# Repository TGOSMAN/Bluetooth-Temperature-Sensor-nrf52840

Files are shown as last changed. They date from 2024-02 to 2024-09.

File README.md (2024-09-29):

```python
import numpy as np
import matplotlib.pyplot as plt
import scipy.signal as signal
```

# Bluetooth Thermometer Design Report

This Notebook, documents the design process and considerationg in making this bluetooth thermometer. The purpose of this project was to be an exercise for PCB design in an IoT environment, and apply the basic stages of product development as an engineer, and enable further development in skills with electronics, DSP, digital design and embedded systems.

### Product Summary
The thermometre device produce, takes a reading from an analogue temperature sensor and broadcast's in an bluetooth low energy advertising packet.Simultaneously, the temperature reading is displayed a quantised temperature level across a row of RGB LED's which can have the colour customised with a BLE connection to the thermometer itself. 
***

## Product Planning
At this stage of development, the functional goals of the product are set. This sets a frameworkfor testing the performance in the later stages, and provides a target to work towards when iteratively improving the systems within the product. The considerations were primarily focused on the user interace with the device due it being the only output of the system and on of the two inputs to the system, hence a strong set of criteria was required.

### Requirements Analysis
|Requirements|Constraints|Needs|
|:-:|:-:|:-:|
|The temperature can be determined visually|Power can only be sourced from a battery or a DC converted source (e.g USB, USB-C, etc)|The device must be able to have customisability for it to blend with its surroundings or to match user preference|
|A alternative user interface can provide user's a reading with an acccuracy of 2 degrees Celsius|The device must have a ridid body so that it is robust and can be mounted|The device only needs to be supplied power for it to start working, with no setup involved|
|The Product must be under $30 to produce|||

### Problem Statement
The problem is to design a product that will assist users to determine the ambient room temperature. The product should give users multiple options to read the temperature, that can be selected based on the effort levels. The product should allow users to customise display methods based on there needs and allow for the product to blend with surrounding home decor. The product may offer many features, however, the central challenge is to measure the temperature and communicate it to a user in different formats at the same time.
***

## Conceptualisation
At this stage, the thermometer's main components and aspects are selected and given detail to assist the detailed design stage. The focus is the overall functions of the product and how that will translate to hardware/software for implementation.

### Concept
The produce developed will have an LED strip that can show the temperature with the LED's colour arrangement along the strip, similar to that of a mercury thermometer.The colour of the LED's will be customisable to match a surrounding colour theme or the user's preference. 

The interface to change the internal settings of the device, will occur over a wireless domain(Bluetooth LE) to provide a low effort requirment and to meet the standards of the 21st century. Since a wireless connection will be required to configure the settings, an efficient use of this domain would be to also communicate the temperature reading with a numerical format. This will allow for a greater accuracy in the reading that will originate from the sensor subsytem itself.

The device will be powered by a wired connection, with a common USB-Type C Connector to supply DC power to the device. This was due to the higher power consumption of LEDs which would drain the battery rather quickly, hence a USB-C provides a highly accessible option for users to connect. 

### High Level Design
As previously discussed the product will be supplied by a USB type-C port to a microcontroller that can interface over bluetooth low energy and via digital signalling with the other subsystems. Each of the other subsytems will be powered by the same USB-C source which will be set to the default 5V supply. 

The temperature sensor will be an analogue sensor from which an ADC will sample it and use this data to then configure the LEDs and advertising packet. The LEDs will be an RGB type to allow for colour changes and contrast to be displayed. A diagram of this is shown below.

<center><image src= "HLD.png" width=45%></image><center>

***

## Hardware Design

### LEDs
The LED selected was the WS2182b. This was selected for its programmable RGB combination and brightness. The WS2182B will be able to take as an input a 24 bit PCM coded stream of data to reflect each of the RGB level for each LED. After the first packet is taken the following packet is transmitted to the next LED. This will allow for the microcontroller to be able to change the colour and brightness of each individual LED without requiring 24 PWM channels continously running. Hence this method is an efficient use of the MCU without a large range of PWM peripherals or an LED controller. Since the signally for the LED's is above 3.3V a level shifter will be required for signally to be shifted and sent to the LED's effectively.

### Microcontroller
The nrf52840 was chosen due to its low cost and detailed documentation available. The Nordic Semiconductor SiC contains an Arm Cortex M4 (64Mhz) CPU  with an integrated 2.4 Ghz Transceiver and Radio Controller that can be easily intefaced with software. This will enable the device to have firmware easily implement and control the BLE transmission mode (2Mbps ,1Mbps etc), along with the bluetooth profile of the device.

The SiC has a 4 Channel PWM Generator that is integrated with DMA for fast and effient signalling. This feature will be used along with the internal PPI(Peripheral Peripheral Interconnect)(Figure 2) to signal to WS2812b LED's and control the sequence period when it is updated.

The NRF52840 has a 12bit ADC placed internally with a maximum sampling rate of 200ksp/s  and a variable analogue gain channel to customise the quantisation level size of the ADC. This function will be used to place the voltage range of the analogue temperature sensor to the gain level required allowing for an optimised resolution. This adc will directly sample the temperature sensor connected to the pin.

### Power Supply
The power supply chosen was an LDO (TLV2117) to ensure a stable and low noise 3.3V source was supplied to the NRF52840, this was chosen due to a USB type-C power source having a high noise level. However, since the WS2812B LED's are a have a high voltage range and are a digital system, the noise level directly from the USB Type-C 5V suppy will suffice to power them.

### Sensor 
The TMP235A was selected as the temperature sensor to be used for its simplicity and low cost. The accuracy of the sensor is $\pm2\degree C$, which will match the criteria identified from the requirements analysis.This sensor can be supplied directly from 3.3V. However, following the data sheet recommendation a 0.1 $\mu F$ decoupling capacitor will be connected to reduce the amount of digital noise that couples to the analogue sensor output. 
The sensor utilises thermal diodes to produce a voltage variation proportional to the temperature. The output of the TMP236 is a buffered output meaning with an output driver designed for direct connection to ADC's and can supply a 1000pF load, hence an interfacing circuit is not required. The specification of the TMP236 specifies for the temperature region being considered the voltage output is $19.5mV / \degree C$ with an offset voltage of 400mV. This can also be written as a linear equation as shown below: 
$$V = 0.0195T + 0.4$$

### PCB Layout Considerations
Key Considerations in the layout of this design were to avoid EMI and transmissoin line effects. Due to the board shape being a long board and each LED being spread evenly along the long dimension of the board.

***

## Firmware Development

### Firmware Structure
The firmware has been written with the use of the nordic NRFx Drivers and the Zephyr real time operating system. The Zephyr RTOS will create and maintain the BLE stack, whilst also allowing for easy creation of threads and memory for efficient power usage. The structure of this firmware contains two main threads, one to manage the notifications and LED signalling of the device and the other ot manage the filtering and ADC use of the device. The Data will be passed between the two threads in a threadsafe manner with the use of a message que. A messsage Que is a simple linked list data structure thats is used to pass a specific struct containing data, between threads. The overall strucutre is illustrated below:

### BLE Configuration
The configuration used for the bluetooth low energy model is a server connectable device. The GATT model includes the environmental sensing primary servie with a temperature charactiristic and a client configuration descriptor within it. This is so that the device can connect and enable regular updates remotely.

### LEDs Signalling
The LEDs chosen are the WS2812B's which have there own RZ (Return to Zero) communication protocol shown in the first figure below. To enable this protocol to effictively the PWM drivers need3e to be used for a custom duty cycle (since this is where the information is stored). In addition to the PWM drivers, a PPI bus connected with a timer to allow for data to be segmented into 24 bit packets to address each LED. The PPI enables the timer and PWM to be reset without a direct CPU intervention. 

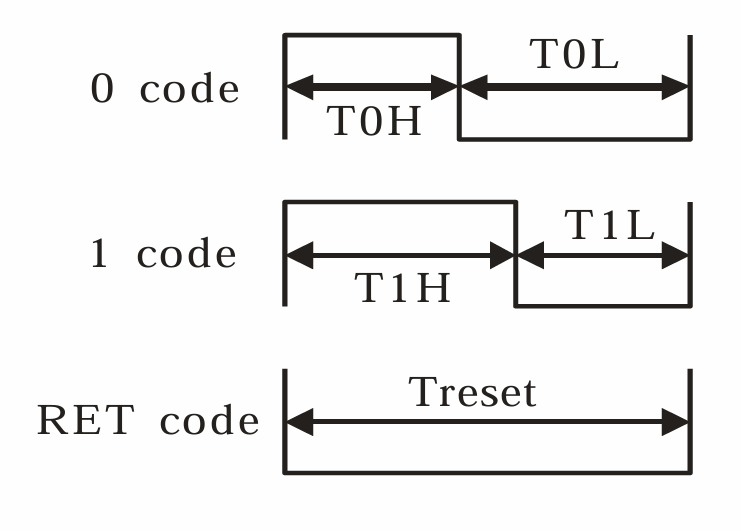
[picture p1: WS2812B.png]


|Symbol|Timing|
 |--|--|
 |T0H|0.4 us|
 |T1H|0.8 us|
 |T0L|0.85 us|
 |T1L|0.45 us|
 |Res| $\ge$ 50us|

The individual LED's each will recieve a packet of 24 bits with 8 bits dedicated to the intensity of each RGB component send by .The WS2812B will store the value of the packet last received also allowing for the LED's to remain unchanged until they are updates with a new packet. This will allow for further power saving since LED signalling will only need to occur at a custom rate and can be slowed down to reduce overal power consumption of the device. With this method the default colours of contrast chosen were red and blue to allow for a clear indication to begin. 

### ADC Sampling
The ADC peripheral in the nRF52840 is a Successive Approximation ADC that has a adjustable resolution and gain. The resolution was set to 12bit with a 2 hz sampling rate in a blocking method due to the low chance that the output will change at high speed. The ADC sampling and conversion is completed in a seperate thread and sent over a workque to the bluetooth and lighting thread to ensure maximum power efficiency. However due to this multithreaded approach the sampling rate will not be precisely 2Hz but have a small variation due to the surrounding instrucutions however this will have minimal magnitude in comparison to the sampling period when the CPU uses a 64Mhz clock. 

The conversion is made by the CPU by first making the data conversion to mV with the formula: $V = Sample \cdot\frac{Gain}{Reference} \cdot \frac{1}{2^{12}}$ 

### Digital Filter Design

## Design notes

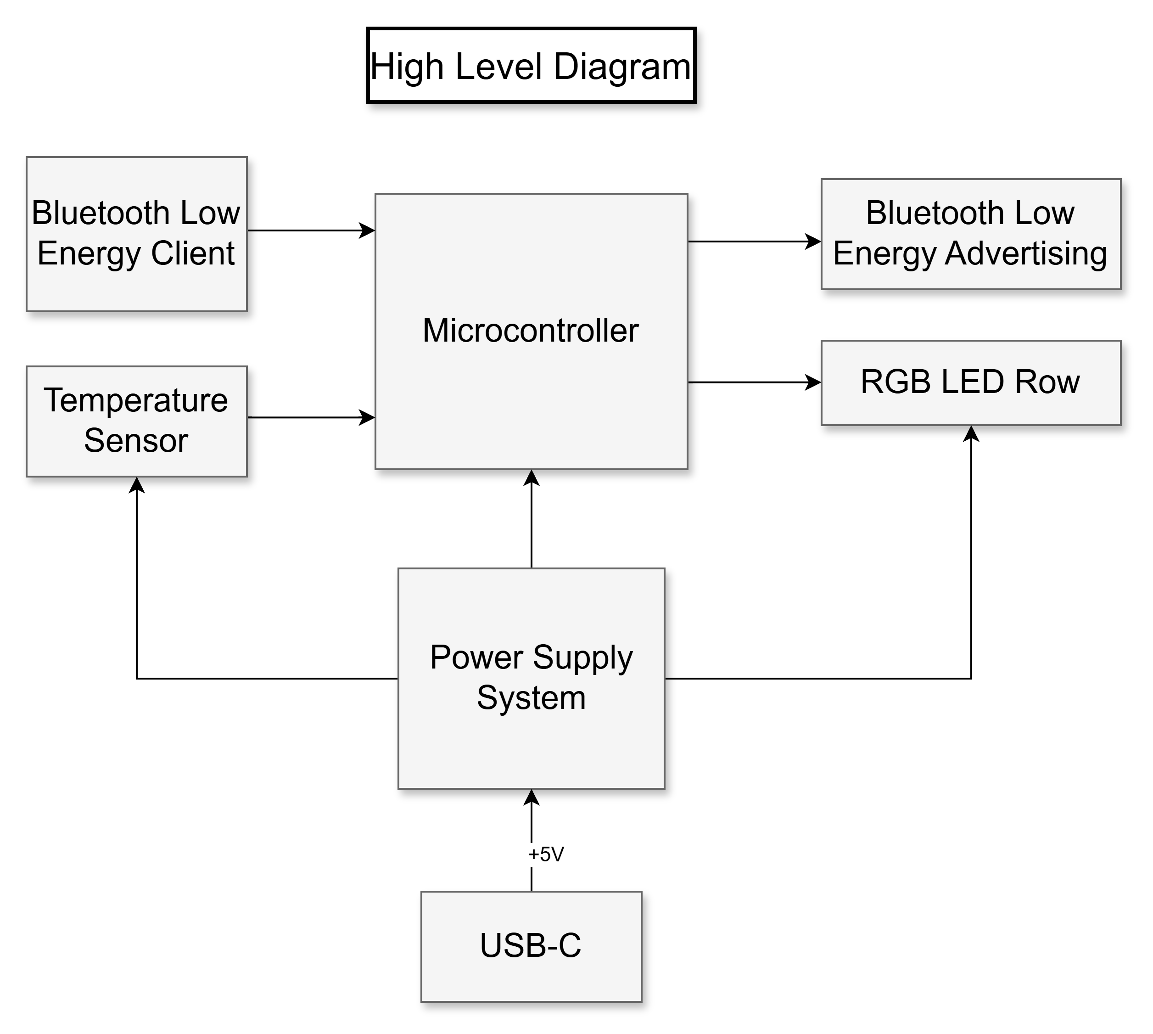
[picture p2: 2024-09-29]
HLD.png

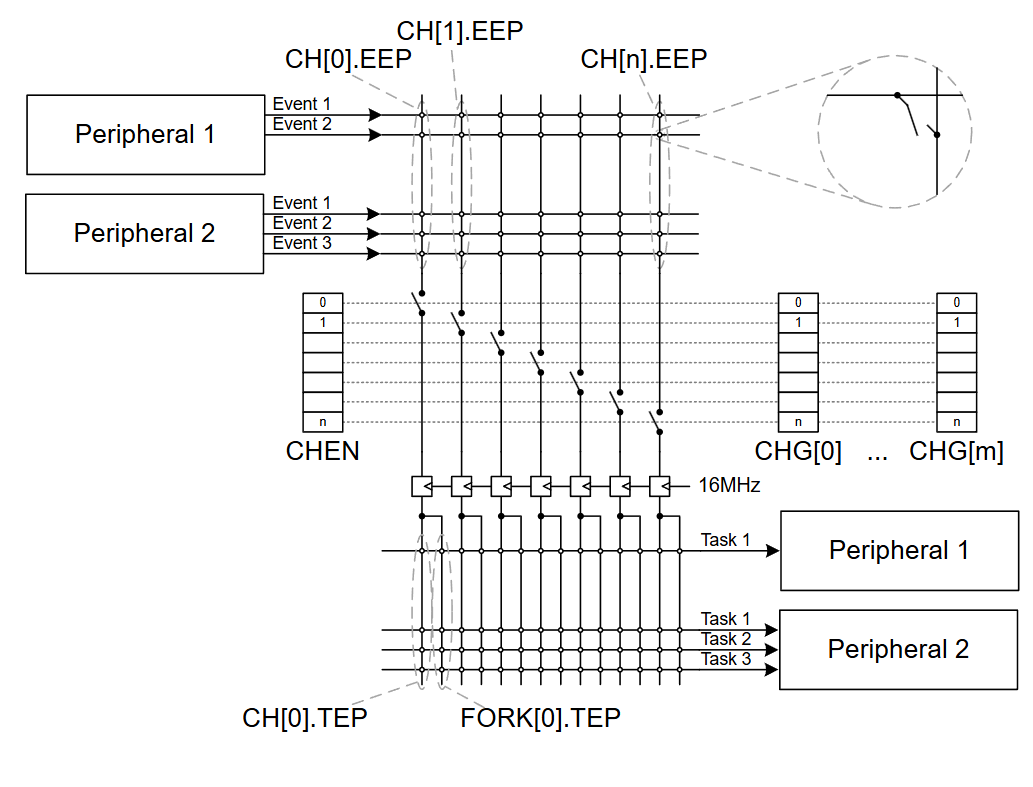
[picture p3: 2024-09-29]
PPI.png

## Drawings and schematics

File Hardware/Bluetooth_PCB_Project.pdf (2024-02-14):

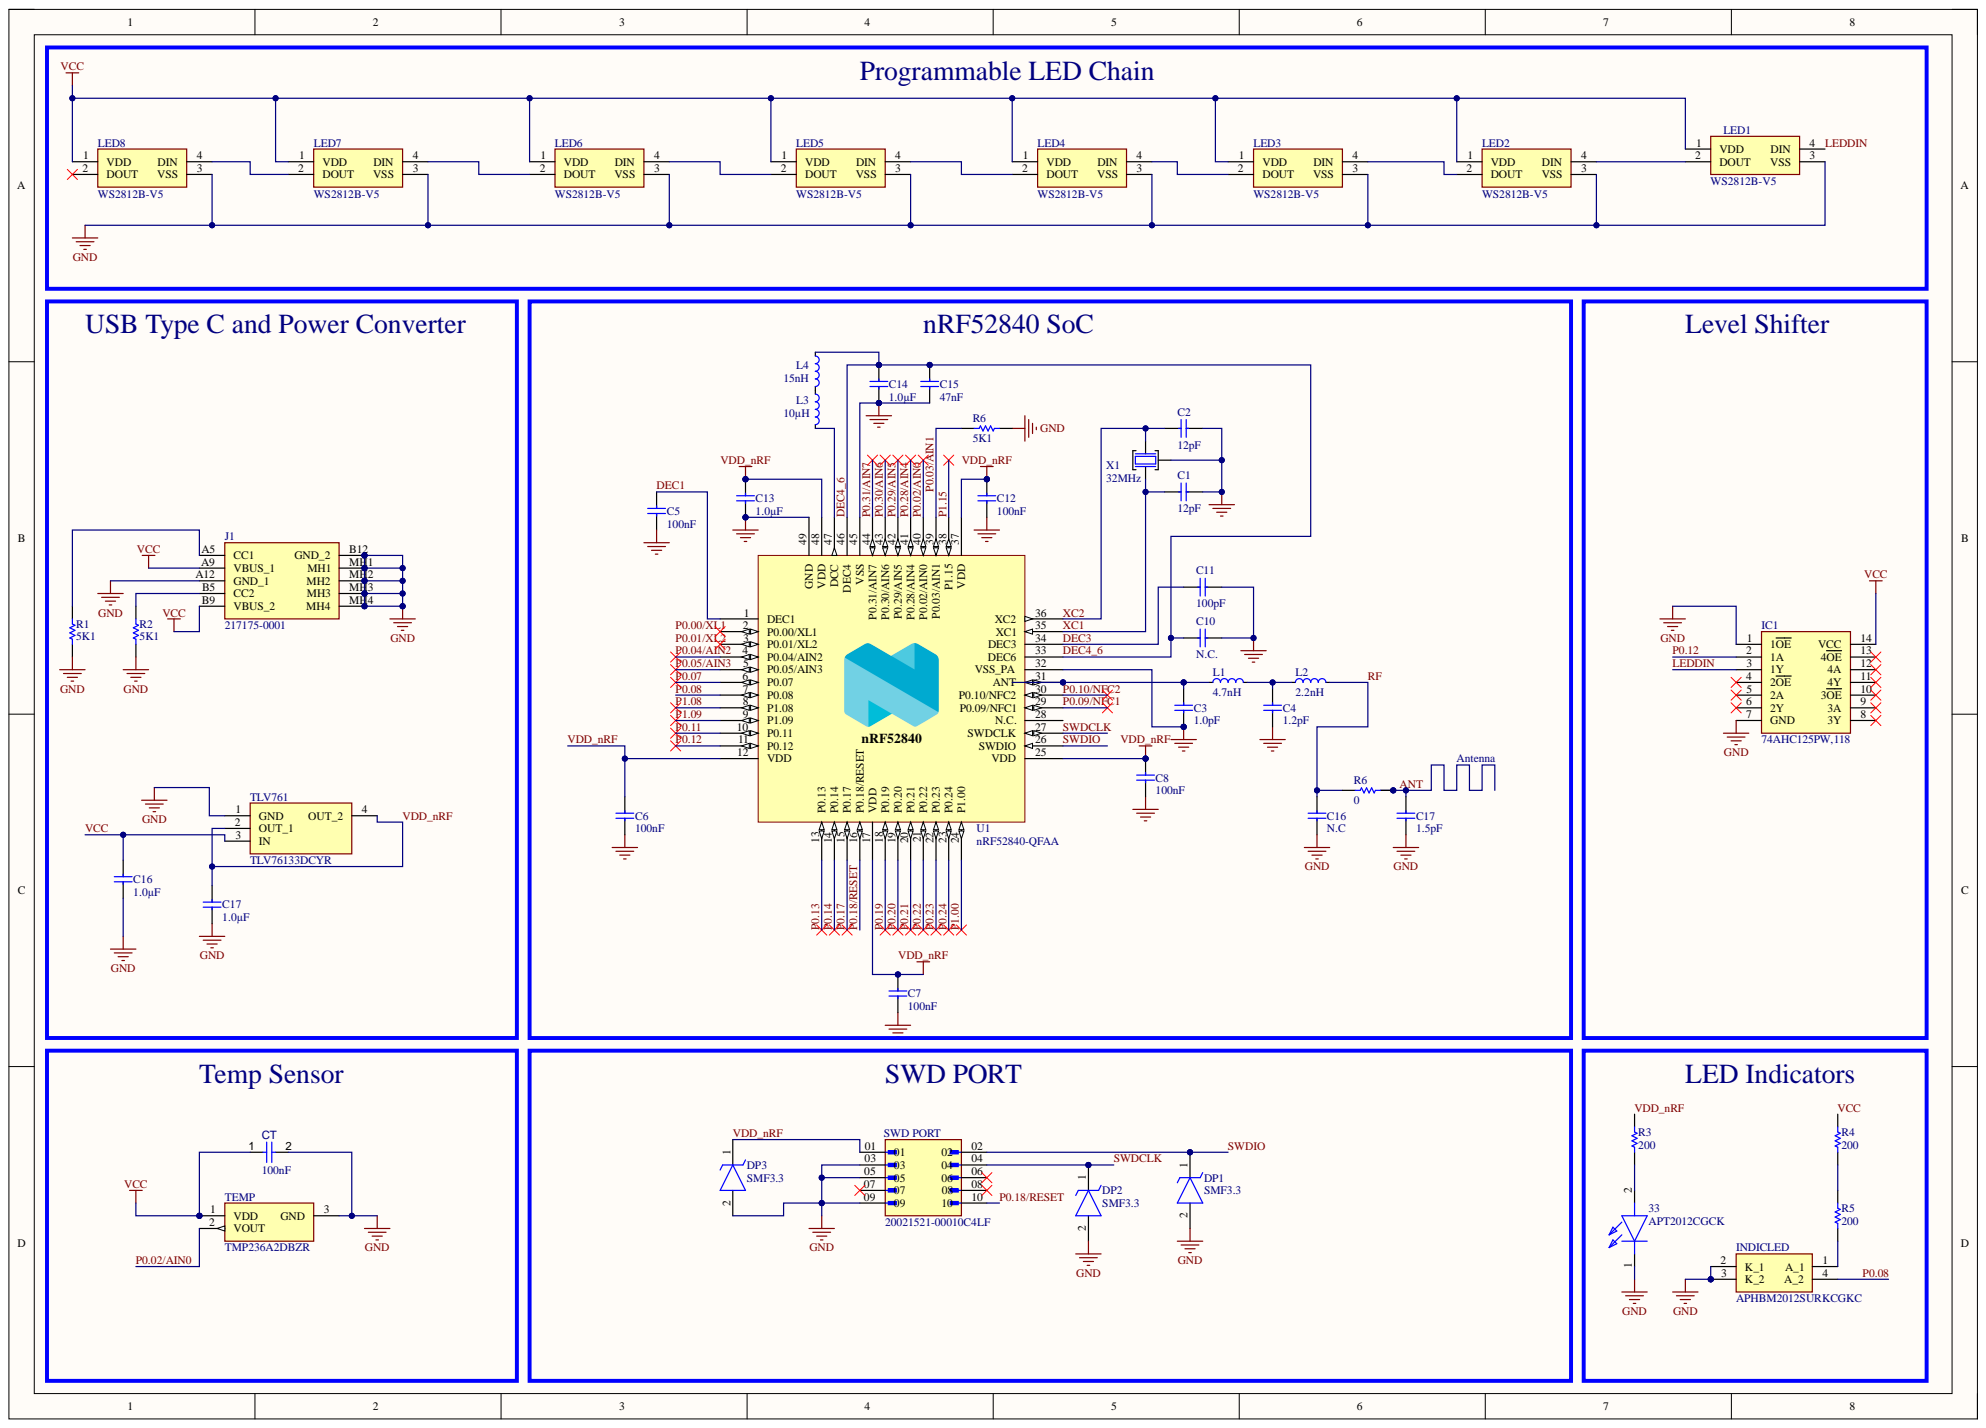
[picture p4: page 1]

VBUS_2 B9

5K1 | VCC

VDD 1

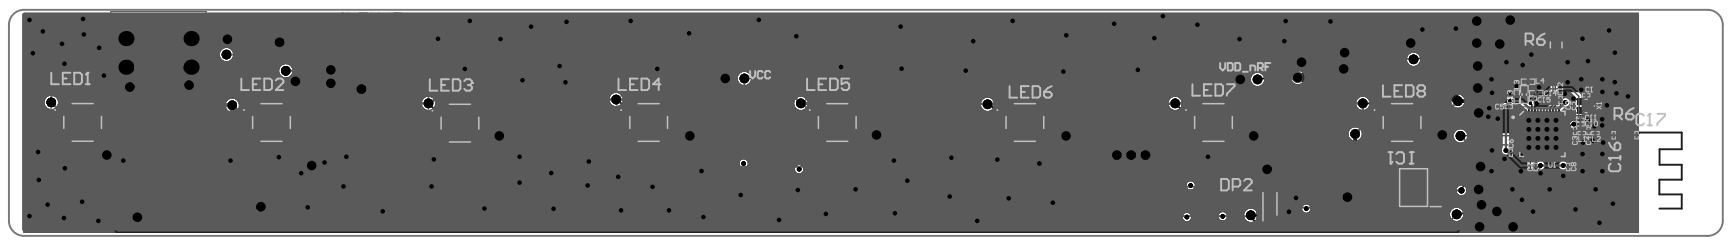
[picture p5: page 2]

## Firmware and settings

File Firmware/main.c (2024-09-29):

#include "hal/nrf_pwm.h"
#include <nrfx_example.h>
#include <nrfx_pwm.h>
#include <stdbool.h>
#include <stdint.h>
//#include <zephyr/drivers/adc.h>
#include <zephyr/drivers/pwm.h>
#include <zephyr/kernel.h>
#include <zephyr/sys/printk.h>
#include "drivers/nrfx_errors.h"
#include <nrfx_glue.h>
#include <nrfx_saadc.h>
#include <helpers/nrfx_gppi.h>
#include <zephyr/bluetooth/bluetooth.h>
#include <zephyr/bluetooth/gap.h>
#include <zephyr/bluetooth/gatt.h>
#include <zephyr/bluetooth/uuid.h>
#include <zephyr/bluetooth/addr.h>
//#include "saadc_examples_common.h"
#include <nrfx_log.h>


#define NRFX_LOG_MODULE                 EXAMPLE
#define NRFX_EXAMPLE_CONFIG_LOG_ENABLED 1
#define NRFX_EXAMPLE_CONFIG_LOG_LEVEL   3
#define STACKSIZE 1024
#define THREAD0_PRIORITY 7
#define THREAD1_PRIORITY 7
#define PWM_INST_IDX 0
#define ARRAYSIZE 192
//#define CH0_AIN ANALOG_INPUT_TO_SAADC_AIN(ANALOG_INPUT_A0)
/* BLUETOOTH SETUP */
/** @brief Temperature Sensor Characteristic UUID. */
#define BT_UUID_TEMPSENSOR_VAL BT_UUID_128_ENCODE(0x00001523, 0x1212, 0xefde, 0x1523, 0x785feabcd123)
#define BT_UUID_TEMP_MYSENSOR_VAL \
	BT_UUID_128_ENCODE(0x00001526, 0x1212, 0xefde, 0x1523, 0x785feabcd123)
#define BT_UUID_TEMPSENSE BT_UUID_DECLARE_128(BT_UUID_TEMPSENSOR_VAL)
#define BT_UUID_TEMP_MYSENSOR       BT_UUID_DECLARE_128(BT_UUID_TEMP_MYSENSOR_VAL)
//Bluetooth Naming Structure
#define DEVICE_NAME CONFIG_BT_DEVICE_NAME
#define DEVICE_NAME_LEN (sizeof(DEVICE_NAME) - 1)
/* PWM SETUP*/
/**
 * @brief Symbol specifying number of times that each duty cycle is to be repeated (after being
 *        played once) and is strictly correlated with the "breath" effect speed.
 */
#define VALUE_REPEATS 0UL
/** @brief Symbol specifying number of loops (breaths) to be performed. */
#define NUM_OF_LOOPS 1UL
/**
 * @brief Symbol specifying number of playbacks to be performed. In this example couple of
 *        playbacks might be considered as one loop.
 */
#define PLAYBACK_COUNT 1UL

/* 
*   @brief Temperature Sensor Notification Properties to be updated and stored
 */
static bool notify_sensor_enabled = false;
static void tempsense_ccc_mysensor_cfg_changed(const struct bt_gatt_attr *attr,
				  uint16_t value)
{
    // Get the value for the the notifciation status and store it in the global variable
	notify_sensor_enabled = (value == BT_GATT_CCC_NOTIFY);
}


struct bt_conn *my_conn = NULL;
//Advertising Packet
static const struct bt_data ad[] = {
        BT_DATA_BYTES(BT_DATA_FLAGS, BT_LE_AD_NO_BREDR),
        BT_DATA(BT_DATA_NAME_COMPLETE, DEVICE_NAME, DEVICE_NAME_LEN),
        BT_DATA_BYTES(BT_DATA_UUID16_ALL, 0x1a, 0x18),
        //BT_DATA(BT_DATA_SVC_DATA16, 0x18, 0x1a), // UUID for Temperature Sensor
       //BT_DATA(BT_, 0x18,0x1a), // UUID for Temperature Sensor
};
int temperature = 0;
static struct bt_le_adv_param *adv_param = BT_LE_ADV_PARAM(
            (BT_LE_ADV_OPT_CONNECTABLE |
            BT_LE_ADV_OPT_USE_IDENTITY), /* Connectable advertising and use identity address */
            BT_GAP_ADV_FAST_INT_MIN_1, /* 0x30 units, 48 units, 30ms */
            BT_GAP_ADV_FAST_INT_MAX_1, /* 0x60 units, 96 units, 60ms */
            NULL); /* Set to NULL for undirected advertising */
//Scan Response Packet
static const struct bt_data sd[] = {
        //BT_DATA(BT_DATA_UUID16_ALL,0x1a,0x18),
       //BT_DATA_BYTES(BT_DATA_UUID16_ALL,0x2a,0x6e),
       //BT_DATA(BT_DATA_SVC_DATA16, 0x18, 0x1a), // UUID for Temperature Sensor
};

BT_GATT_SERVICE_DEFINE(tempsensor_svc, BT_GATT_PRIMARY_SERVICE(BT_UUID_ESS),

	/*BT_GATT_CHARACTERISTIC(BT_UUID_TEMP_MYSENSOR, BT_GATT_CHRC_NOTIFY, BT_GATT_PERM_NONE, NULL,
			       NULL, NULL),*/
    BT_GATT_CHARACTERISTIC(BT_UUID_TEMPERATURE, BT_GATT_CHRC_READ | BT_GATT_CHRC_NOTIFY, BT_GATT_PERM_NONE, NULL, NULL, NULL),
	BT_GATT_CCC(tempsense_ccc_mysensor_cfg_changed, BT_GATT_PERM_READ | BT_GATT_PERM_WRITE),

);

//Bluetooth connection callback's
void on_connected(struct bt_conn *conn, uint8_t err)
{
    if (err) {
        //LOG_ERR("Connection error %d", err);
        return;
    }
    //LOG_INF("Connected");
    my_conn = bt_conn_ref(conn);
    return;
    /* STEP 3.2  Turn the connection status LED on */
}

void on_disconnected(struct bt_conn *conn, uint8_t reason)
{
    //LOG_INF("Disconnected. Reason %d", reason);
    bt_conn_unref(my_conn);
    return;
    /* STEP 3.3  Turn the connection status LED off */
}



struct bt_conn_cb connection_callbacks = {
    .connected              = on_connected,
    .disconnected           = on_disconnected,
};

int tempsensor_send_sensor_notify(uint32_t sensor_value)
{
	if (!notify_sensor_enabled) {
		return -EACCES;
	}

	return bt_gatt_notify(NULL, &tempsensor_svc.attrs[2], 
			      &sensor_value,
			      sizeof(sensor_value));
}


//create a global PWM instance
nrfx_pwm_t pwm_instance1 = NRFX_PWM_INSTANCE(PWM_INST_IDX);
typedef struct {
    int temp_reading;
} SensorReading;
K_MSGQ_DEFINE(device_message_queue, sizeof(SensorReading), 16, 4);
// Global PWM configuration setup
// 1 PWM period is 1.25us, clco8k period is 62.5ns
// automatic stepping
nrfx_pwm_config_t config1 = {    
    .output_pins = {LED1_PIN},
    .pin_inverted = {1},
    .irq_priority = 7,
    .base_clock = NRF_PWM_CLK_16MHz,
    .count_mode = NRF_PWM_MODE_UP,
    .top_value = 20,
    .load_mode = NRF_PWM_LOAD_COMMON,
    .step_mode = NRF_PWM_STEP_AUTO,
    .skip_gpio_cfg = 0
};

// Mutex definition of variable synchronisation/ control over critical code section timing
K_MUTEX_DEFINE(key);
nrf_pwm_values_common_t pwm_val []=
{
    0, 0, 0, 0, 0, 0, 0, 0,0, 0, 0, 13, 6, 13, 6, 13, 6, 6, 13, 13, 13, 13, 6, 13
};
static nrf_pwm_values_common_t reset_seq [55] = {0};
nrf_pwm_values_common_t pwm_array_val [192] = {0};
nrf_pwm_values_common_t pwm_array_val2 [192] = {0};

// Led Array Build Function:
/*
Inputs:
    nrf_pwm__values_common_t *array: Pointer to array[0] to store signal PWM duty cycles as one big block to send as a continouse signal
    int lednumber: number where it sits in the LED strip 0-7 to place the colour sequnce in teh correct order
    nrf_pwm__values_common_t *coloursignal: pointer to coloursignal[0] which is the 24 element array that holds the colour value for 1 LED
Outputs:
    none
Description:
    concatenates each LED colour setup array as one big block of a pwm duty cycle sequence to be sent as a continous signal due to the WS2812 signalling
*/
void configurePPI(void){
    uint8_t pwm_stop_ppi_channel;
    nrfx_err_t err = nrfx_gppi_channel_alloc(&pwm_stop_ppi_channel);
    if (err != NRFX_SUCCESS) {
        LOG_ERR("nrfx_gppi_channel_alloc error: %08x", err);
        return;
    }
    nrfx_gppi_channel_endpoints_setup(pwm_stop_ppi_channel,nrfx_pwm_event_address_get(&pwm_instance1, NRF_PWM_EVENT_SEQEND0),
                                  nrf_pwm_task_address_get(pwm_instance1.p_reg,  NRF_PWM_TASK_STOP));

    nrfx_gppi_channels_enable(BIT(pwm_stop_ppi_channel));
}
void ledarraybuild(nrf_pwm_values_common_t *array,int lednumber,nrf_pwm_values_common_t *coloursignal){
    int base;
    base = 24*lednumber;
    for(int i = 0; i < 24; i++){
        array[base + i] = coloursignal[i];
    }
    return;
}

// Colour Sequence Function:
/*
Inputs:
    nrf_pwm__values_common_t *val: Pointer to val[0], which is a 24 element array of uint16_t values to store individual duty cycles in
    uint8_t red: Red component of a colour RGB hex code for ease of use
    uint8_t green: Green component of a colour RGB hex code for ease of use
    uint8_t blue: Blue component of a colour RGB hex code for ease of use
    
Outputs:
    none
Description:
    Adds appropriate duty cycle values in an array to represent a colour for one LED from a hex code
    to match the WS2812 signalling protocol. This is inverted as it appears the PWM signal has an 
    an inversion at some point. High should be VH for ~800ns, Low should be VH for ~400ns, this is designated
    from the hex code with the correct ordering as well.
*/
void colour_sequence(nrf_pwm_values_common_t *val, uint8_t red, uint8_t green, uint8_t blue){

    for(int i = 7; i >= 0; i--){
        //redblock
        if((red&(0x80>>i))){
            val[i + 8] = 5;
        } else {
            val[i + 8] = 15;
        }
    
        // blue block
        if((blue&(0x80>>i))){
            val[i + 16] = 5;
        } else {
            val[i + 16] = 15; 
        }
        // green block
        if((green&(0x80>>i))){
            val[i] = 5;
        } else {
            val[i] = 15;
        }
    }
    return;
}

//once PWM has a loop event this is triggered to setup a looped PWM.-> we need to change this to not be looping
//currently set to only loop once
static void pwm_handler(nrfx_pwm_evt_type_t event_type, void * p_context)
{
    nrfx_pwm_t * inst = p_context;

}


static void ledupdate(uint32_t highcolour, uint32_t lowcolour, int level){
    static nrf_pwm_values_common_t pwm_array_val [192] = {0};
    nrf_pwm_sequence_t const seq_set =
    {
        .values = {pwm_array_val},
        .length = NRFX_ARRAY_SIZE(pwm_array_val),
        .repeats = VALUE_REPEATS,
        .end_delay = 0
    };
    //PWM0->PSEL
    for(int i = 0; i < 8; i++){
        colour_sequence(pwm_val, (uint8_t)((highcolour&(0xFF000000))>>24), (uint8_t)((highcolour&(0x00FF0000))>>16), (uint8_t)((highcolour&(0x0000FF00))>>8));
        
        //colour_sequence(pwm_val, 0x01, 0x0F, 0x01);
        ledarraybuild(pwm_array_val, i, pwm_val);
    }
    for(int i = 0; i < level; i++){
        colour_sequence(pwm_val, (uint8_t)((lowcolour&0xFF000000)>>24), (uint8_t)((lowcolour&0x00FF0000)>>16), (uint8_t)((lowcolour&0x0000FF00)>>8));
        //colour_sequence(pwm_val,0x0F, 0x00, 0x00);
        ledarraybuild(pwm_array_val, i, pwm_val);
    } 

    nrfx_pwm_simple_playback(&pwm_instance1, &seq_set, PLAYBACK_COUNT, NRFX_PWM_FLAG_LOOP);

    
    //nrfx_pwm_stop(&pwm_instance, true);
    //nrfx_pwm_sequence_update(&pwm_instance, 0,&seq_set);
    return;
}


//Thread to change the colour based on the ADC value/ Temperature
void thread0(void)
{
    #if defined(__ZEPHYR__)
    IRQ_CONNECT(NRFX_IRQ_NUMBER_GET(NRF_PWM_INST_GET(PWM_INST_IDX)), IRQ_PRIO_LOWEST,
                NRFX_PWM_INST_HANDLER_GET(PWM_INST_IDX), 0, 0);
    #endif
    nrfx_err_t status;
    (void) status;
    int temp;
    k_mutex_lock(&key, K_FOREVER);
    configurePPI();
    k_mutex_unlock(&key);

    //NRFX_EXAMPLE_LOG_INIT();

    //NRFX_LOG_INFO("Starting nrfx_pwm example for sequence loaded in common mode.");
    //NRFX_EXAMPLE_LOG_PROCESS();
    //colour_sequence(pwm_val, 0x00, 0x00, 0xFF);
    
    //nrfx_pwm_config_t config = NRFX_PWM_DEFAULT_CONFIG(LED1_PIN, LED2_PIN, LED3_PIN, LED4_PIN);
    status = nrfx_pwm_init(&pwm_instance1, &config1, pwm_handler, &pwm_instance1);
    NRFX_ASSERT(status == NRFX_SUCCESS);
    NRF_PWM0->PSEL.OUT[0] = 0x0000000C;// fix for bug which moves the PIN to 0xD
    k_mutex_lock(&key, K_FOREVER);
    //LOG_HEXDUMP_INF(pwm_array_val, sizeof(pwm_array_val),"Thread0 Data");
    /* nrfx_pwm_simple_playback(&pwm_instance, &seq_set1, PLAYBACK_COUNT, NRFX_PWM_FLAG_LOOP);
    k_busy_wait(20000);*/
    int i = 0;
    //ledupdate(0xFF, 0X00, (4));
    k_mutex_unlock(&key);
 
    // at the moment set not to change as the LEDS can't update -> focus on getting ADC to work.
	while (1) {
        i++;
        nrfx_err_t ret = k_msgq_get(&device_message_queue, &temp, K_FOREVER);
        if (ret){
            LOG_ERR("Return value from k_msgq_get = %d",ret);
        }
        k_mutex_lock(&key, K_FOREVER);
        ledupdate(0x0000FF00, 0xFF000000, (temp*8)/40);
        k_msleep(50);
        
        k_mutex_unlock(&key);
        k_msleep(100);
        //k_busy_wait(20000);

	}
}

static int16_t sample;
static nrfx_saadc_channel_t channel = NRFX_SAADC_DEFAULT_CHANNEL_SE(NRF_SAADC_INPUT_AIN0, 0);
//Thread to configure ADC and to filter + convert the sensor value to a temperature.
void thread1(void)
{   
    
    //status value for errors
            /* STEP 5.1 - Connect ADC interrupt to nrfx interrupt handler */
        k_mutex_lock(&key, K_FOREVER);
        #if defined(__ZEPHYR__)
        IRQ_CONNECT(DT_IRQN(DT_NODELABEL(adc)),
		    DT_IRQ(DT_NODELABEL(adc), priority),
		    nrfx_isr, nrfx_saadc_irq_handler, 0);
        #endif
        /* STEP 5.2 - Connect ADC interrupt to nrfx interrupt handler */
        nrfx_err_t err = nrfx_saadc_init(DT_IRQ(DT_NODELABEL(adc), priority));
        if (err != NRFX_SUCCESS) 
        {
                printk("nrfx_saadc_mode_trigger error: %08x", err);
                return;
        }
        k_mutex_unlock(&key);
        /* STEP 5.3 - Configure the SAADC channel */
        channel.channel_config.gain = NRF_SAADC_GAIN1_6;
        err = nrfx_saadc_channels_config(&channel, 1);
        if (err != NRFX_SUCCESS) 
        {
		    printk("nrfx_saadc_channels_config error: %08x", err);
	        return;
	    }

        /* STEP 5.4 - Configure nrfx_SAADC driver in simple and blocking mode */
        err = nrfx_saadc_simple_mode_set(BIT(0),
                                         NRF_SAADC_RESOLUTION_12BIT,
                                         NRF_SAADC_OVERSAMPLE_DISABLED,
                                         NULL);
        if (err != NRFX_SUCCESS) {
                printk("nrfx_saadc_simple_mode_set error: %08x", err);
                return;
        }
        
        /* STEP 5.5 - Set buffer where sample will be stored */
        err = nrfx_saadc_buffer_set(&sample, 1);
        if (err != NRFX_SUCCESS) {
                printk("nrfx_saadc_buffer_set error: %08x", err);
                return;
        }
        k_mutex_lock(&key, K_FOREVER);
        bt_conn_cb_register(&connection_callbacks);


        err = bt_enable(NULL);
        if (err) {	
            LOG_ERR("Bluetooth init failed (err %d)\n", err);	
            return;
            }
            LOG_INF("Bluetooth initialized\n");
        //wait_xtal_to_start();
        k_mutex_unlock(&key);
        err = bt_le_adv_start(adv_param, ad, ARRAY_SIZE(ad), sd, ARRAY_SIZE(sd));
            if (err) {		
                LOG_ERR("Advertising failed to start (err %d)\n", err);		
                return;	
            }	
        while(1){
            nrfx_err_t err = nrfx_saadc_mode_trigger();
            if (err != NRFX_SUCCESS) {
                    printk("nrfx_saadc_mode_trigger error: %08x", err);
                    return;
            }
            k_mutex_lock(&key,K_FOREVER);
            /* STEP 7.3 - Calculate and print voltage */
            int voltage = ((600*6) * sample) / ((1<<12));
            uint32_t temp = (voltage - 500)/19.5;
            temperature = temp;
            nrfx_err_t ret = k_msgq_put(&device_message_queue,&temp, K_FOREVER);
            if (ret){
                LOG_ERR("Return value from k_msgq_put = %d",ret);
            }
            tempsensor_send_sensor_notify(temp);
            //bt_le_adv_update_data(ad, ARRAY_SIZE(ad), sd, ARRAY_SIZE(sd));
            k_mutex_unlock(&key);
            k_msleep(500);
        }

    }
   K_THREAD_DEFINE(thread0_id, STACKSIZE, thread0, NULL, NULL, NULL,
		THREAD0_PRIORITY, 0, 0);
   K_THREAD_DEFINE(thread1_id, STACKSIZE, thread1, NULL, NULL, NULL,
		THREAD1_PRIORITY, 0, 0);

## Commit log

2024-01-23 Added ADC Sample
2024-09-05 Working Bluetooth and Temperature Output Files
2024-09-07 Added LED Explanation
2024-09-07 Updated with diagrams on LED Section
2024-09-21 ADC information ADDED
